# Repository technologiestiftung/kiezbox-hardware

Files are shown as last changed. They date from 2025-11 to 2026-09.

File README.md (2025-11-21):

# kiezbox-pcb
This folder contains the wiring diagrams for the hardware components. The folders can be opened with KiCad. One is for the sensor module and one is for the Kiezbox core. There is also a PFD showing the layout of the hardware in the control cabinet. It also shows where to drill the holes for the solar cable and the hole for the outdoor temperature sensor.

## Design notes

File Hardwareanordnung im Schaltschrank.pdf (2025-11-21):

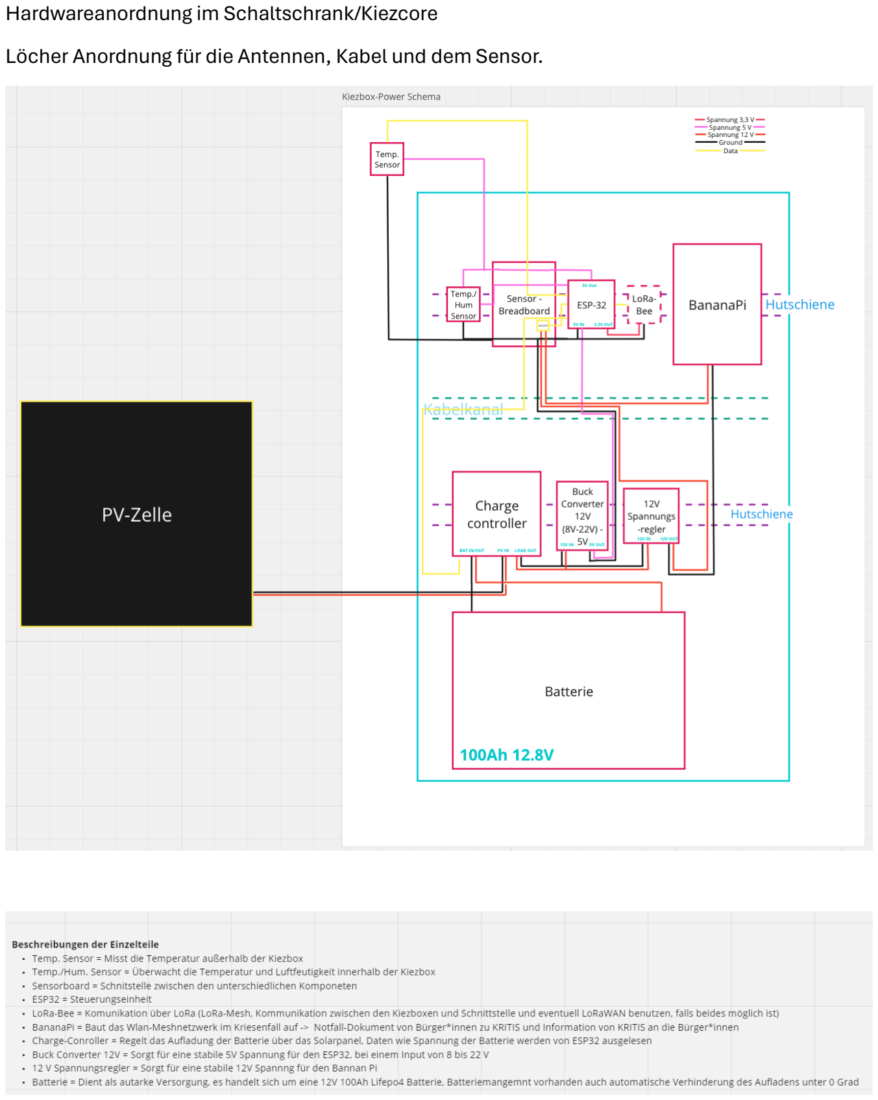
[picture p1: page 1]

Hardwareanordnung im Schaltschrank/Kiezcore
Löcher Anordnung für die Antennen, Kabel und dem Sensor.

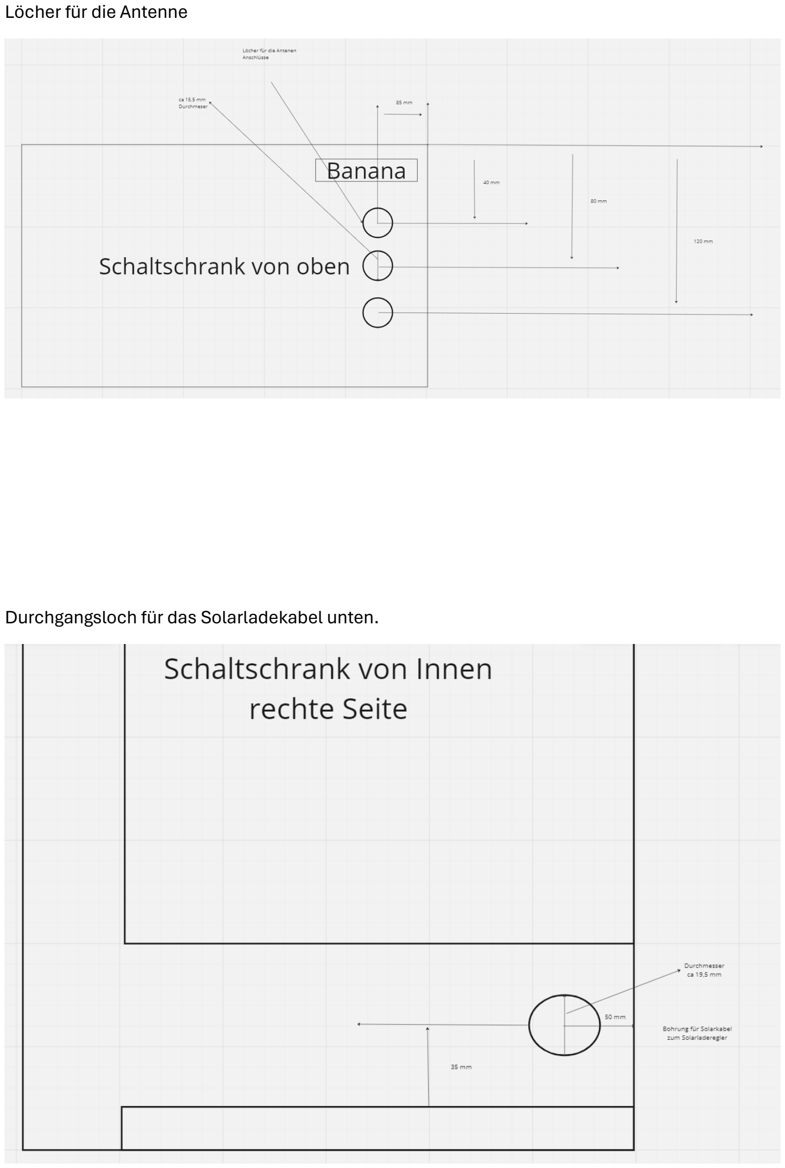
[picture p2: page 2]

Löcher für die Antenne

Durchgangsloch für das Solarladekabel unten.

Loch für den Außentemperatursensor oben (Der Sensor befindet sich im zwischen Bereich)

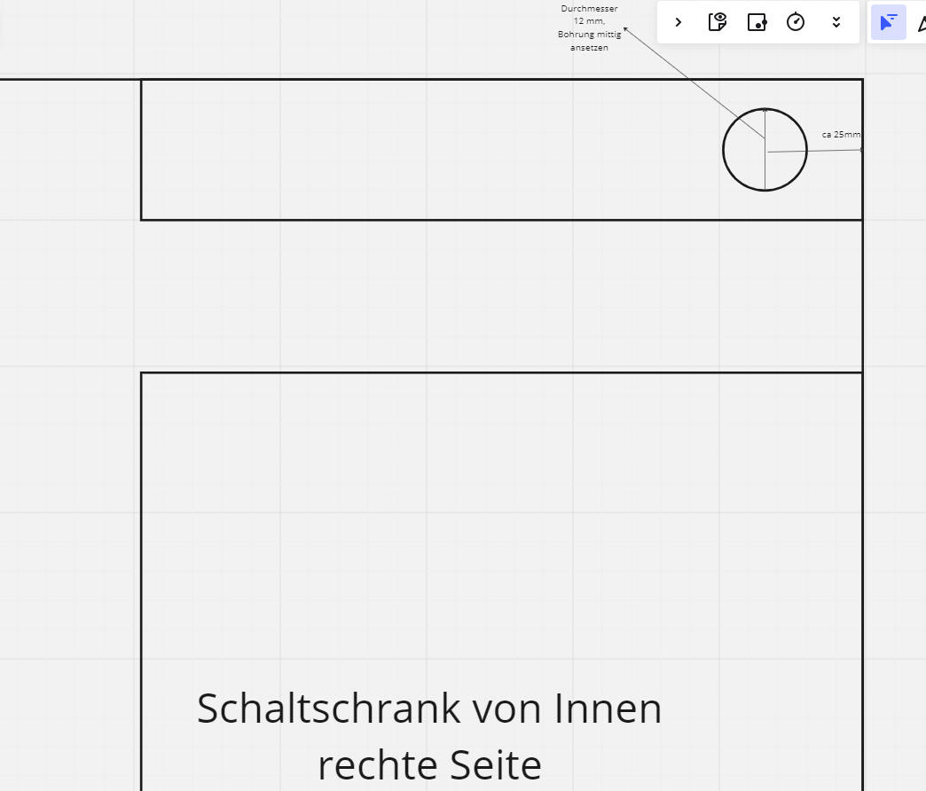
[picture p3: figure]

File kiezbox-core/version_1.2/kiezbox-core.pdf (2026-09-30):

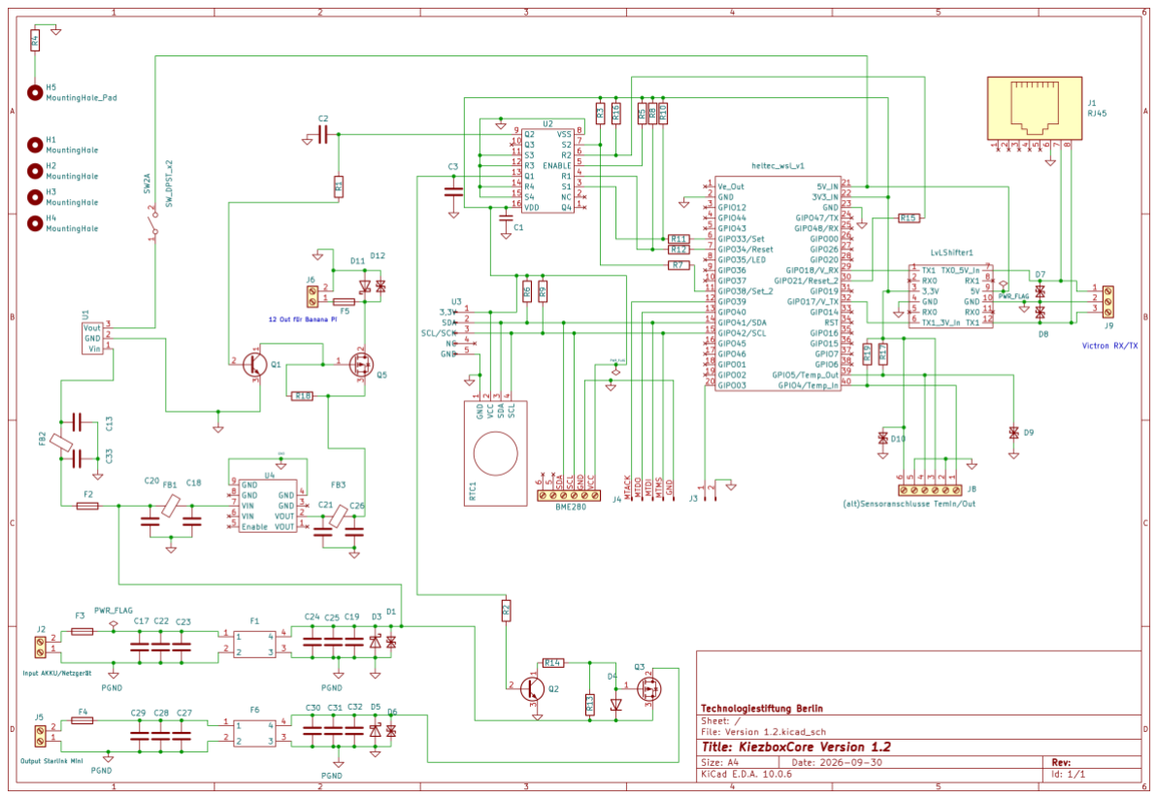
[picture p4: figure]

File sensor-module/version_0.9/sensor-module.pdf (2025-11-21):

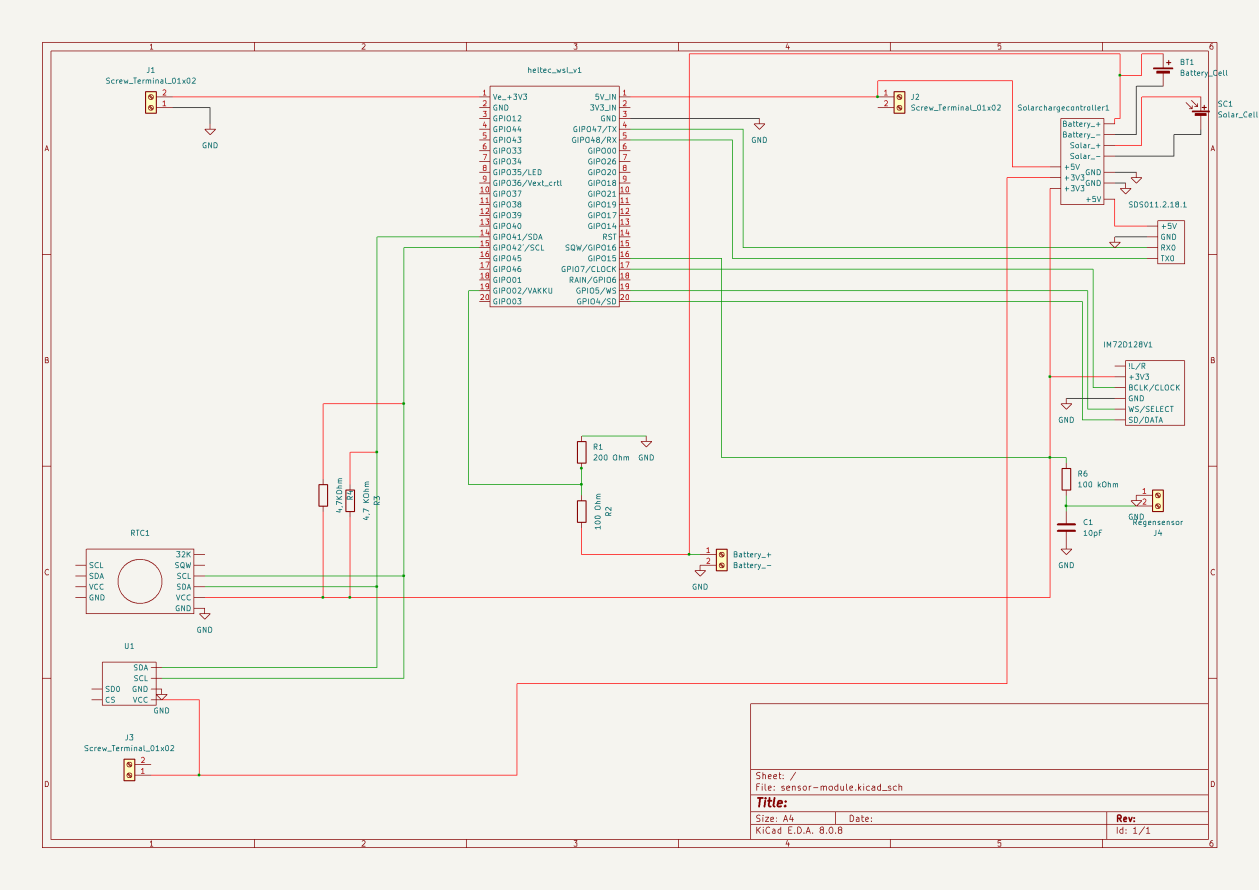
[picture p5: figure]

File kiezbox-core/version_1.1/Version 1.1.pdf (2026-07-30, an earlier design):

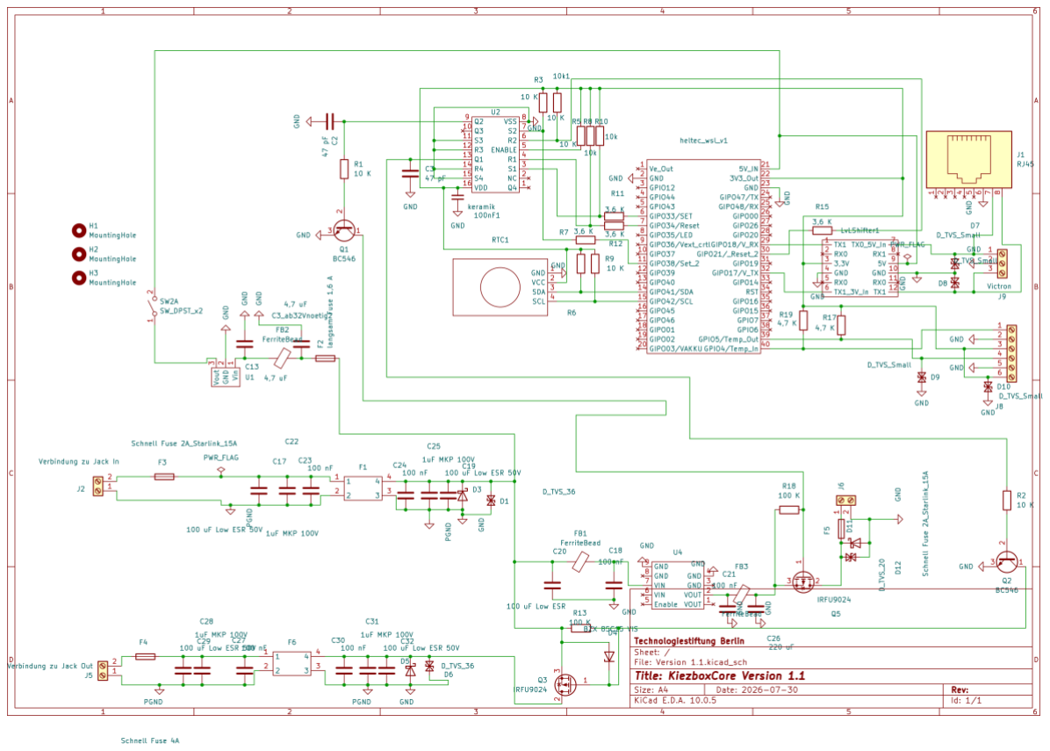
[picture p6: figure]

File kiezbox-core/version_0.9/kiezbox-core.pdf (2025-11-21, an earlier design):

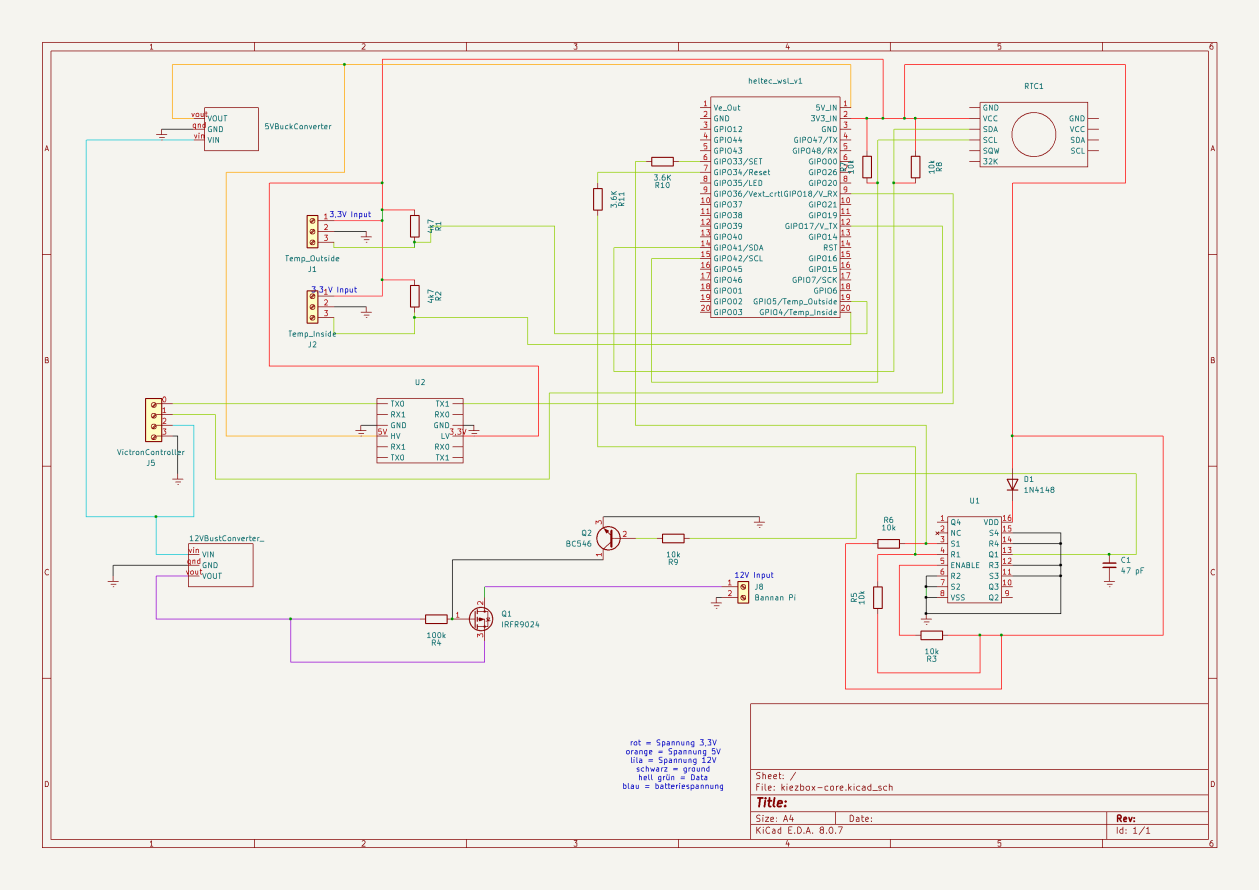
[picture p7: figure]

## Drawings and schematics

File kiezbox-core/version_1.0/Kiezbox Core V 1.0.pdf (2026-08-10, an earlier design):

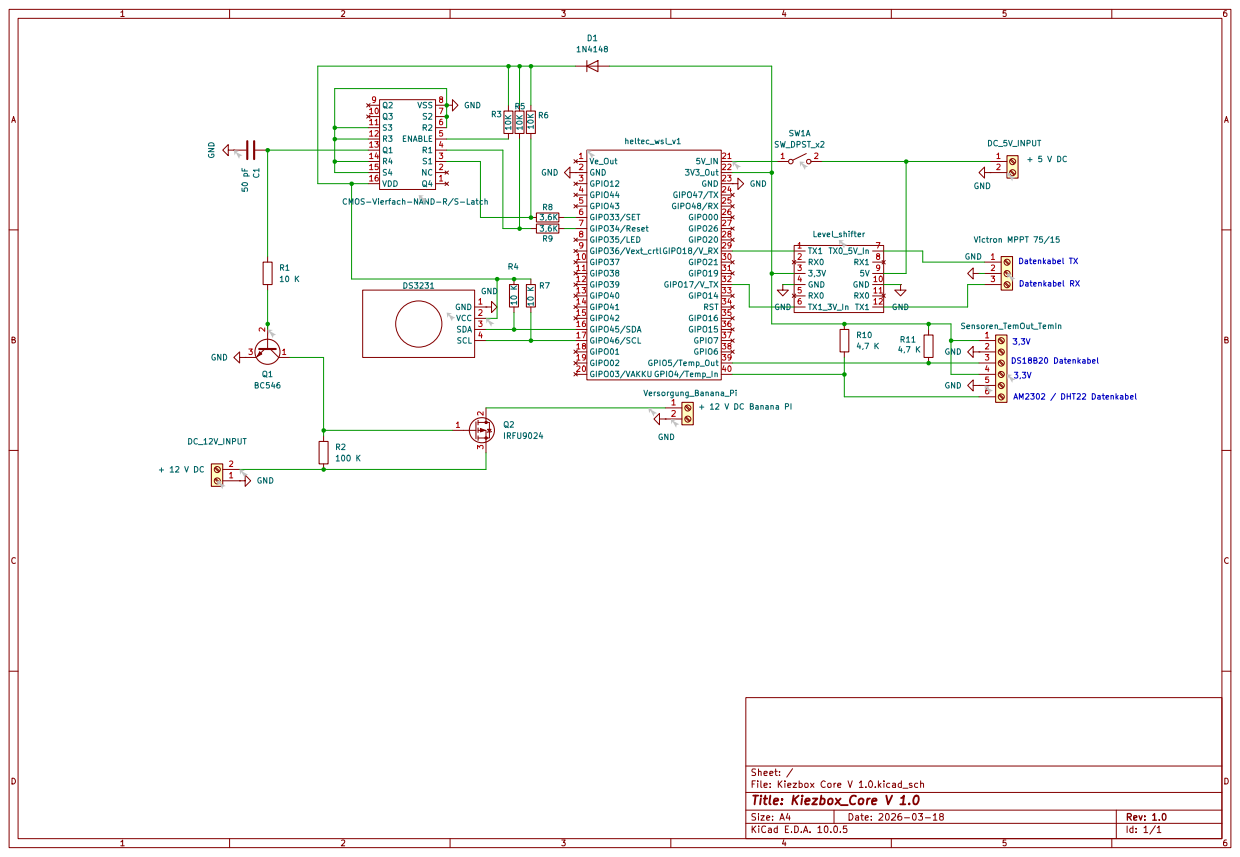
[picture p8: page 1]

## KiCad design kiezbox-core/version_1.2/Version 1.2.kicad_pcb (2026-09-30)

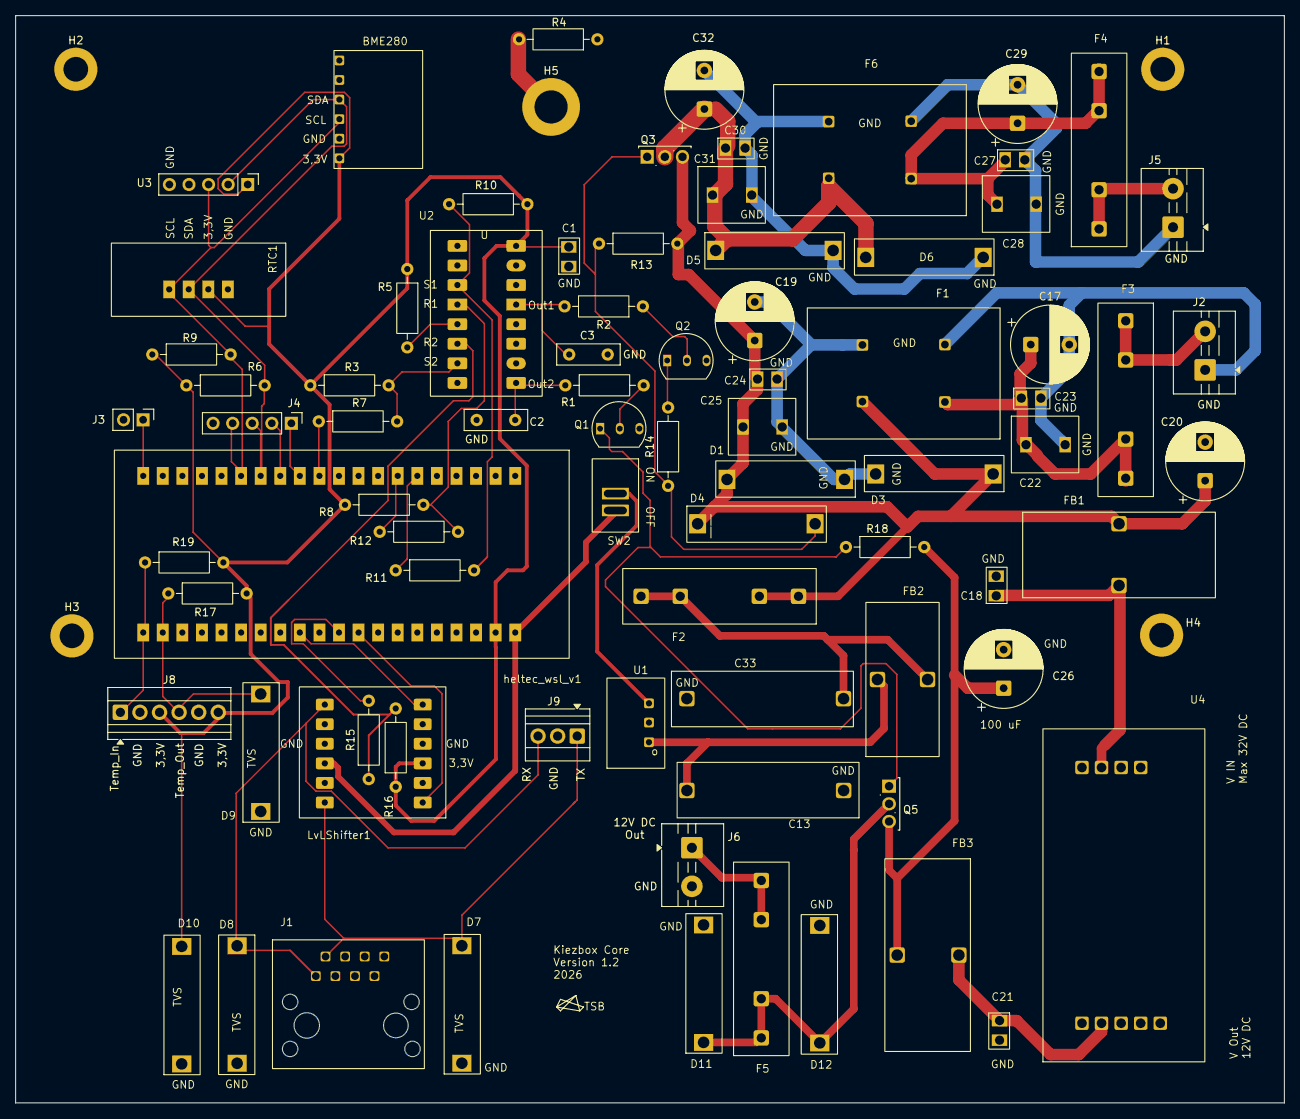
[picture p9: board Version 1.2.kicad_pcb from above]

Board: 2 copper layers, 164.6 x 141.1 mm, 86 parts (0 on the bottom side), 45 nets.

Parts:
BME280: BME280
C1, C18, C21, C23, C24, C27, C30: 100 nF; 100nF
C2, C3: 47 pF; C_Disc_D8.0mm_W2.5mm_P5.00mm
C13, C33: 4,7 uF
C17, C19, C20, C26, C29, C32: 100 uF; CP_Radial_D10.0mm_P5.00mm
C22, C25, C28, C31: 1uF
D1, D6: D_TVS_36; TVS_groß
D3, D5: D_Schottky 40V 5A; TVS_groß
D4: BZX 85C15 VIS; TVS_groß
D7, D8, D9, D10: TVS; TVS_groß
D11: D_Schottky 20V 3A; TVS_groß
D12: TVS 20,5V; TVS_groß
F1, F6: Netzdrossel, 1mH, 6A; Filter_Leistung
F2: 1,6 A; Sicherunghalter
F3: Schnell Fuse 5A; Sicherunghalter
F4: 3,15 A träge; Sicherunghalter
F5: Schnell Fuse 2A_Starlink_15A; Sicherunghalter
FB1, FB3: Funk-Entstördrossel, 6 A, 100 µH; Filter polo
FB2: Ringkerndrosseln TLC 2,5A - 10 µH; Filter TSR
H1, H2, H3, H4: MountingHole; MountingHole_3.2mm_M3_DIN965_Pad
H5: MountingHole_Pad; MountingHole_4.3mm_M4_DIN965_Pad
J1: RJ45
J2: Input AKKU/Netzgerät; TerminalBlock_MaiXu_MX126-5.0-02P_1x02_P5.00mm
J3: JTAG Modus Auswahl; PinHeader_1x02_P2.54mm_Vertical
J4: JTAG-Schnittstelle; PinHeader_1x05_P2.54mm_Vertical
J5: Output Starlink Mini; TerminalBlock_MaiXu_MX126-5.0-02P_1x02_P5.00mm
J6: 12 Out für Banana Pi; TerminalBlock_MaiXu_MX126-5.0-02P_1x02_P5.00mm
J8: (alt)Sensoranschlusse TemIn/Out; TerminalBlock_Xinya_XY308-2.54-6P_1x06_P2.54mm_Horizontal
J9: Victron RX/TX; TerminalBlock_Xinya_XY308-2.54-3P_1x03_P2.54mm_Horizontal
LvLShifter1: lvlshifter
Q1, Q2: BC546; Transistor
Q3, Q5: IRFU9024; TO-251-3_Vertical
R1, R2, R5, R6, R9: 10 K; R_Axial_DIN0207_L6.3mm_D2.5mm_P10.16mm_Horizontal
R3, R16: 10K; R_Axial_DIN0207_L6.3mm_D2.5mm_P10.16mm_Horizontal
R4: 0; R_Axial_DIN0207_L6.3mm_D2.5mm_P10.16mm_Horizontal
R7, R11, R12, R15: 3,6 K; R_Axial_DIN0207_L6.3mm_D2.5mm_P10.16mm_Horizontal
R8, R10: 10k; R_Axial_DIN0207_L6.3mm_D2.5mm_P10.16mm_Horizontal
R13, R18: 100 K; R_Axial_DIN0207_L6.3mm_D2.5mm_P10.16mm_Horizontal
R14: 47k; R_Axial_DIN0207_L6.3mm_D2.5mm_P10.16mm_Horizontal
R17, R19: 4,7 K; R_Axial_DIN0207_L6.3mm_D2.5mm_P10.16mm_Horizontal
RTC1: RTC
SW2: SW_DPST_x2; Unbenannt
U1: DC/DC-Wandler TSR-1, 1 W, 5 V, 1000 mA, SIL / TO-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; TSR1-2450
U2: CMOS-Vierfach-NAND-R/S-Latch, 3 - 18 V, 6,8mA, DI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; Latch 16 Pin
U3: DS3231 Real Time Clock Modul für Raspberry Pi; PinHeader_1x05_P2.54mm_Vertical
U4: Pololu 12V Step-Up Step-Down Spannungsregler S18V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; Pololu12
heltec_wsl_v1: Heltec_v3_lite

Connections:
GND: BME280.GND, C1.1, C2.2, C3.2, C13.1, C17.2, C18.2, C19.2, C20.2, C21.2, C22.2, C23.2, C24.2, C25.2, C26.2, C27.2, C28.2, C29.2, C30.2, C31.2, C32.2, C33.1, D1.1 (A1), D3.2 (A), D5.2 (A), D6.1 (A1), D7.1 (A1), D8.2 (A2), D9.1 (A1), D10.1 (A1), D11.2 (A), D12.1 (A1), F1.2, F1.3, F6.2, F6.3, J1.6, J2.1, J3.2, J4.5, J5.1, J6.2, J8.2 (GND), J8.5 (GND), J9.2 (GND), LvLShifter1.4 (GND), LvLShifter1.10 (GND), Q1.3 (E), Q2.3 (E), R4.1, RTC1.1 (GND), U1.2 (GND), U2.8 (VSS), U2.11 (S3), U2.12 (R3), U2.14 (R4), U2.15 (S4), U3.5 (GND), U4.4 (GND), U4.9 (GND), heltec_wsl_v1.2 (GND), heltec_wsl_v1.23 (GND)
unnamed: BME280.VCC (3,3V_Input), C1.2, D10.2 (A2), J8.3 (3,3V), J8.6 (3,3V), LvLShifter1.3 (3,3V), R3.1, R5.1, R6.1, R8.1, R9.1, R10.1, R16.1, R17.2, R19.2, RTC1.2 (VCC), U2.16 (VDD), U3.1 (3,3V), heltec_wsl_v1.22 (3V3_IN)
unnamed: C17.1, C22.1, C23.1, F1.1, F3.2
unnamed: C27.1, C28.1, C29.1, F4.2, F6.1
unnamed: C33.2, F2.2, FB2.2
unnamed: C19.1, C20.1, C24.1, C25.1, D1.2 (A2), D3.1 (K), D4.1 (K), F1.4, F2.1, FB1.1, Q3.3 (S), R13.2
unnamed: D4.2 (A), Q3.1 (G), R13.1, R14.1
unnamed: C30.1, C31.1, C32.1, D5.1 (K), D6.2 (A2), F6.4, Q3.2 (D)
unnamed: D7.2 (A2), J1.7, J9.1 (TX), LvLShifter1.7 (TX0_5V_In)
unnamed: D8.1 (A1), J1.8, J9.3 (RX), LvLShifter1.12 (TX1)
unnamed: D9.2 (A2), J8.4 (Temp_Out), R17.1, heltec_wsl_v1.39 (GPIO5/Temp_Out)
unnamed: D11.1 (K), D12.2 (A2), F5.1, Q5.2 (D)
unnamed: H5.1 (1_1), R4.2
unnamed: F3.1, J2.2
unnamed: J3.1, heltec_wsl_v1.20 (GIPO03)
unnamed: J4.1, heltec_wsl_v1.12 (GIPO39)
unnamed: J4.2, heltec_wsl_v1.13 (GIPO40)
unnamed: BME280.SDA, J4.3, R6.2, RTC1.3 (SDA), U3.2 (SDA), heltec_wsl_v1.14 (GIPO41/SDA)
unnamed: BME280.SCL, J4.4, R9.2, RTC1.4 (SCL), U3.3 (SCL/SCK), heltec_wsl_v1.15 (GIPO42/SCL)
unnamed: F4.1, J5.2
unnamed: F5.2, J6.1
unnamed: LvLShifter1.9 (5V), SW2.2 (B), heltec_wsl_v1.21 (5V_IN)
unnamed: LvLShifter1.6 (TX1_3V_In), heltec_wsl_v1.32 (GIPO17/V_TX)
unnamed: Q1.2 (B), R1.2
unnamed: Q1.1 (C), Q5.1 (G), R18.1
unnamed: Q2.2 (B), R2.1
unnamed: Q2.1 (C), R14.2
unnamed: C26.1, FB3.2, Q5.3 (S), R18.2
unnamed: SW2.1 (A), U1.3 (Vout)
unnamed: C13.2, FB2.1, U1.1 (Vin)
unnamed: R5.2, U2.5 (ENABLE)
unnamed: C3.1, R2.2, U2.13 (Q1)
unnamed: C2.1, R1.1, U2.9 (Q2)
unnamed: R8.2, R12.2, U2.4 (R1)
unnamed: R15.1, R16.2, U2.6 (R2)
unnamed: R10.2, R11.2, U2.3 (S1)
unnamed: R3.2, R7.2, U2.7 (S2)
unnamed: C18.1, FB1.2, U4.7 (VIN)
unnamed: C21.1, FB3.1, U4.2 (VOUT)
unnamed: LvLShifter1.1 (TX1), heltec_wsl_v1.29 (GIPO18/V_RX)
unnamed: R15.2, heltec_wsl_v1.30 (GIPO21/Reset_2)
unnamed: R11.1, heltec_wsl_v1.6 (GIPO33/Set)
unnamed: R12.1, heltec_wsl_v1.7 (GIPO34/Reset)
unnamed: R7.1, heltec_wsl_v1.11 (GIPO38/Set_2)
unnamed: J8.1 (3,3V), R19.1, heltec_wsl_v1.40 (GPIO4/Temp_In)

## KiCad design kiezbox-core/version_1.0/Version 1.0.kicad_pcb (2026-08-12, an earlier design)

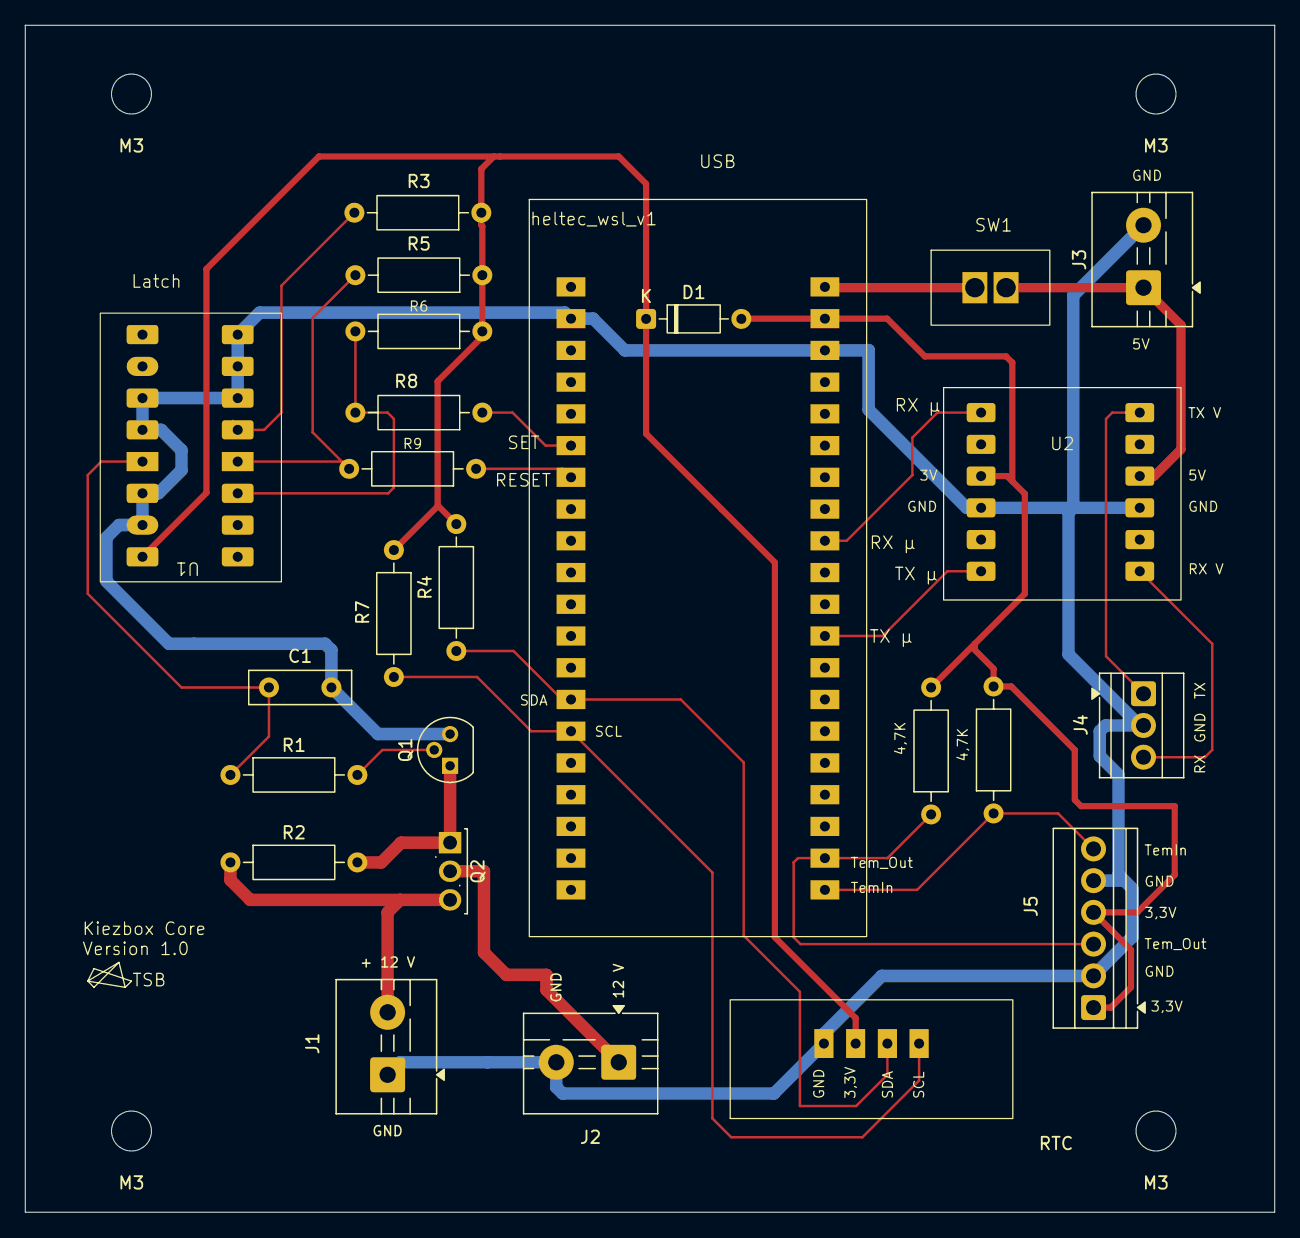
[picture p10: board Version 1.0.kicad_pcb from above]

Board: 2 copper layers, 100.0 x 95.0 mm, 29 parts (0 on the bottom side), 23 nets.

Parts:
C1: 47 pF; C_Disc_D8.0mm_W2.5mm_P5.00mm
D1: 1N4148; D_DO-35_SOD27_P7.62mm_Horizontal
J1: 12 V In; TerminalBlock_MaiXu_MX126-5.0-02P_1x02_P5.00mm
J2: 12 Out; TerminalBlock_MaiXu_MX126-5.0-02P_1x02_P5.00mm
J3: 5V; TerminalBlock_MaiXu_MX126-5.0-02P_1x02_P5.00mm
J4: Victron; TerminalBlock_Xinya_XY308-2.54-3P_1x03_P2.54mm_Horizontal
J5: Sensoren_TemOut_TemIn; TerminalBlock_Xinya_XY308-2.54-6P_1x06_P2.54mm_Horizontal
M3, M3#2, M3#3, M3#4: MountingHole_3.2mm_M3
Q1: BC546; TO-92
Q2: IRFU9024; TO-251-3_Vertical
R1, R3, R4, R7: 10 K; R_Axial_DIN0207_L6.3mm_D2.5mm_P10.16mm_Horizontal
R2: 100 K; R_Axial_DIN0207_L6.3mm_D2.5mm_P10.16mm_Horizontal
R5, R6: 10k; R_Axial_DIN0207_L6.3mm_D2.5mm_P10.16mm_Horizontal
R8, R9: 3,6 K; R_Axial_DIN0207_L6.3mm_D2.5mm_P10.16mm_Horizontal
R10, R11: 4,7 K; R_Axial_DIN0207_L6.3mm_D2.5mm_P10.16mm_Horizontal
RTC1: RTC
SW1: SW_DPST_x2; Unbenannt
U1: Latch 16 Pin
U2: lvlshifter
heltec_wsl_v1: Heltec_v3_lite

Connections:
GND: C1.2, J1.1, J2.2, J3.2, J4.2 (GND), J5.2 (GND), J5.5 (GND), Q1.3 (E), RTC1.1 (GND), U1.6 (R2), U1.7 (S2), U1.8 (VSS), U1.11 (S3), U1.12 (R3), U1.14 (R4), U1.15 (S4), U2.4 (GND), U2.10 (GND), heltec_wsl_v1.2 (GND), heltec_wsl_v1.23 (GND)
unnamed: D1.2 (A), J5.1 (3,3V_Input), J5.4 (3,3V), R10.2, R11.2, U2.3 (3,3V), heltec_wsl_v1.22 (3V3_Out)
unnamed: D1.1 (K), R3.1, R4.1, R5.1, R6.1, R7.1, RTC1.2 (VCC), U1.16 (VDD)
unnamed: J1.2, Q2.3 (S), R2.1
unnamed: J2.1, Q2.2 (D)
unnamed: J3.1, SW1.2 (B), U2.9 (5V)
unnamed: J4.3 (RX), U2.12 (TX1)
unnamed: J4.1 (TX), U2.7 (TX0_5V_In)
unnamed: J5.6 (Temp_IN), R10.1, heltec_wsl_v1.40 (GPIO4/Temp_In)
unnamed: J5.3 (Temp_OUT), R11.1, heltec_wsl_v1.39 (GPIO5/Temp_Out)
unnamed: Q1.2 (B), R1.2
unnamed: Q1.1 (C), Q2.1 (G), R2.2
unnamed: R7.2, RTC1.4 (SCL), heltec_wsl_v1.15 (GIPO42/SCL)
unnamed: R4.2, RTC1.3 (SDA), heltec_wsl_v1.14 (GIPO41/SDA)
unnamed: SW1.1 (A), heltec_wsl_v1.21 (5V_IN)
unnamed: R3.2, U1.5 (ENABLE)
unnamed: C1.1, R1.1, U1.13 (Q1)
unnamed: R5.2, R9.2, U1.4 (R1)
unnamed: R6.2, R8.2, U1.3 (S1)
unnamed: U2.6 (TX1_3V_In), heltec_wsl_v1.32 (GIPO17/V_TX)
unnamed: U2.1 (TX1), heltec_wsl_v1.29 (GIPO18/V_RX)
unnamed: R8.1, heltec_wsl_v1.6 (GIPO33/SET)
unnamed: R9.1, heltec_wsl_v1.7 (GIPO34/Reset)

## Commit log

2025-11-21 Revise README for hardware component details
    Updated README to provide detailed information about wiring diagrams and hardware layout.
2026-07-29 update KiCad files of the new pcb version
    [kiezbox-core.kicad_pcb, kiezbox-core.kicad_sch]
2026-07-30 Add files via upload
    New PCB Version 1.1
    [Version 1.1.kicad_pcb, Version 1.1.kicad_sch]
2026-07-30 New PCB Version 1.1
    [Version 1.1.kicad_pcb, Version 1.1.kicad_sch]
2026-08-12 chore: restructure repo for better versioning
    [Version 1.1.kicad_pcb, Version 1.1.kicad_sch, kiezbox-core.kicad_pcb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]
2026-08-12 update file to new circuit diagram
    [Version 1.0.kicad_pcb, Version 1.0.kicad_sch]
2026-09-30 version 1.2
    [Version 1.2.kicad_pcb, Version 1.2.kicad_sch]
